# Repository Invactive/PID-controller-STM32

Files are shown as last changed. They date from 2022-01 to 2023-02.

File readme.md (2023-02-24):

# PID controller project - resistor temperature control

Temperature controller with PID regulator and live data logger. Implemented on development board NUCLEO-STM32F767ZI.

## Features
- Temperature setting via UART serial communication or phisical encoder (default start temperature is 20℃)
- Monitoring current measured value via UART serial communication
- Display of setpoint and current temperature on LCD display
- Python script for logging live data and displaying measured signals on graph
- Automatic control system controlled by a software-designed PID controller

## Components
-	Development board NUCLEO-STM32F767ZI
-	Ceramic heating resistor 22Ω, 5W
-	Power supply AC/DC - 5,7V/800mA DC
-	Supply module for contact plates MB102
-	Transistor MOSFET IRF520N
-	Temperature sensor (digital - I2C) BMP280
-	Rotary encoder
- Display - LCD 1602A

## Electrical schematics
[Schematics](./Screens_pdfs_txts/Schematics.pdf)

## Photos
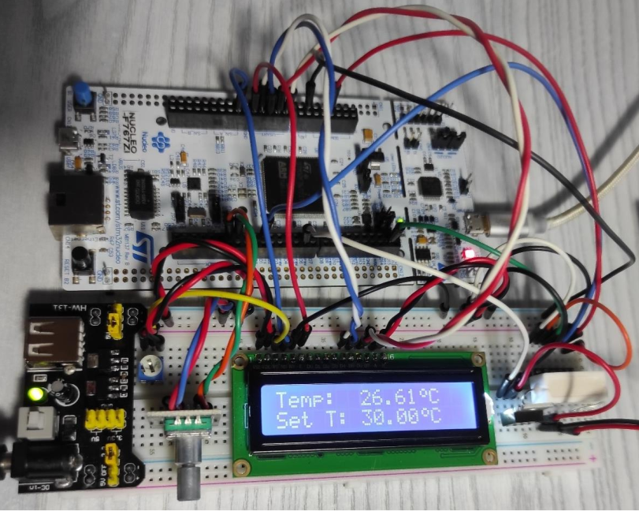
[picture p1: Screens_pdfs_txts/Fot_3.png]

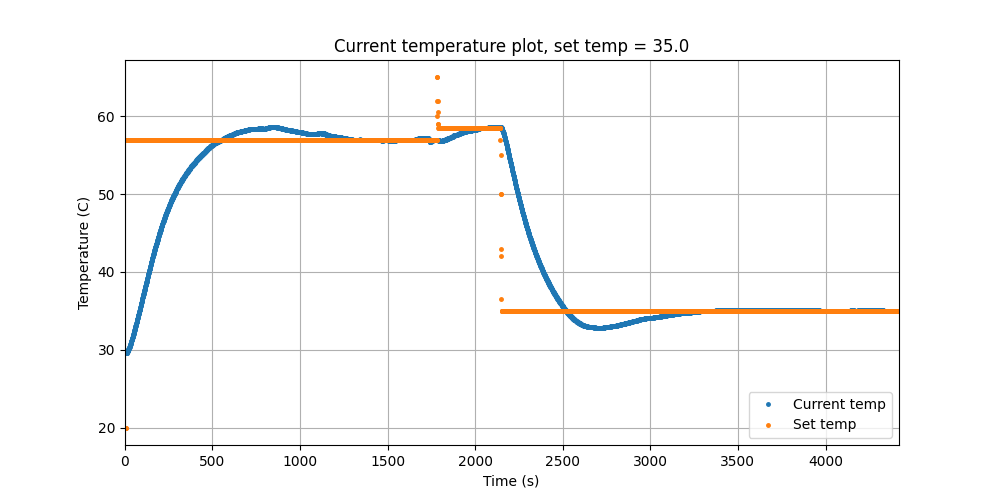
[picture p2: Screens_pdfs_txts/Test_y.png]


## Demonstration video
[Demo video on Youtube](https://youtu.be/86S8K2vb8bY)

## Resources:
- https://os.mbed.com/platforms/ST-Nucleo-F767ZI/
- https://msalamon.pl/dziecinnie-prosta-sprzetowa-obsluga-enkodera-na-stm32/
- https://www.electronics-tutorials.ws/pl/tranzystor/mosfet-jako-przelacznik.html
- https://msalamon.pl/dostalismy-swietna-obsluge-przerwania-uart-idle-w-halu/
-	https://matplotlib.org/stable/index.html
-	https://www.researchgate.net/profile/Chris_Cox6/publication/316658102_First_order_plus_dead_time_FOPDT_model_parameter_estimation/links/5b2275ed0f7e9b0e37423cf6/Firs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

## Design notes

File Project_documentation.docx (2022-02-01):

Sprawozdanie z laboratorium | | Rok akademicki 2021/22
Przedmiot: Systemy mikroprocesorowe
Temat projektu: Projekt regulatora PID – regulacja temperatury rezystora | | Ostateczny termin złożenia: 31.01.2021
Wydział, kierunek, semestr, grupa: WARiE, AiR, sem. 5, Gr. A1/L2 | Imię i Nazwisko: 1. Jakub Grzesiak | Punkty:
Data złożenia ćwiczenia: 31.01.2022

1. Cel projektu

Celem projektu było zbudowanie i przetestowanie demonstracyjnego systemu sterowania i pomiaru temperatury obiektu cieplnego (rezystora) w oparciu o mikrokontroler z rodziny STM32. Zadaniem zaimplementowanego regulatora PID była regulacja temperatury z uchybem do 1% wartości zakresu regulacji. Do realizacji celu użyto płytkę ewaluacyjną NUCLEO-STM32F767ZI. Do symulacji i sprawdzania pomiarów posłużył Matlab i Python.

2. Spis użytych elementów
- Płytka ewaluacyjna NUCLEO-STM32F767ZI
- Rezystor ceramiczny 22 Ω , 5W
- Zasilacz sieciowy 5,7V/800mA DC
- Moduł zasilania MB102
- Tranzystor MOSFET IRF520N
- Czujnik temperatury BMP280
- Enkoder obrotowy
- Wyświetlacz LCD 1602A
3. Funkcjonalności projektu
- Zadawanie temperatury za pomocą komunikacji szeregowej UART lub enkodera (domyślna temperatura startowa to 20℃ , max. 65℃ )
- Podgląd aktualnej wartości mierzonej za pomocą komunikacji szeregowej UART
- Wyświetlanie zadawanej oraz aktualnej temperatury na wyświetlaczu LCD
- Skrypt Python do logowania danych na żywo i graficznego przedstawiania sygnałów pomiarowych
- Układ automatycznej regulacji sterowany za pomocą programowo zaprojektowanego regulatora PID
- System kontroli wersji GitHub
4. Schemat elektroniczny

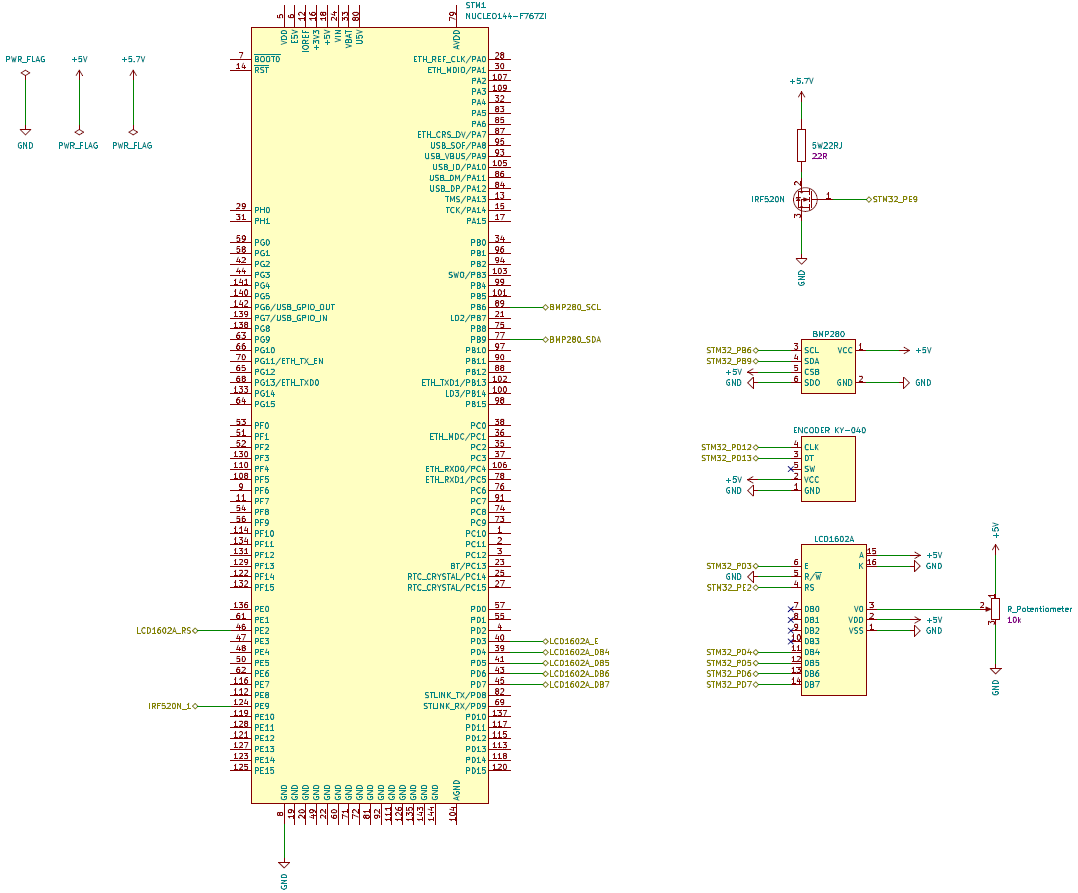
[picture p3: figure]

Schemat elektroniczny wykonano w programie KiCAD. Plik PDF schematu znajduje się w głównym folderze z dokumentacją.

Rysunek 1. Schemat elektroniczny projektu

5. Skrypt Python do logowania danych na żywo

Skrypt posiada następujące funkcjonalności:

- Pozwala na zadanie żądanej wartości temperatury
- Odczytuje aktualną oraz zadaną wartość temperatury przesyłaną przez port szeregowy COM z mikroprocesora
- Zapisuje czas od uruchomienia, aktualną wartość temperatury z czujnika oraz wartość zadaną temperatury do pliku .csv
- Wykreśla graficzny przebieg temperatury mierzonej przez czujnik BMP280 na żywo

Przy starcie skryptu należy podać numer portu szeregowego COM z którego pobierane będą dane oraz zadać temperaturę jaką ma osiągnąć obiekt (zakres od 20 do 65 ℃ ). Do działania skryptu wymagane jest posiadanie bibliotek w nim użytych – gdy nie są zainstalowane można użyć narzędzia pip install. Do wczytywania danych i wysyłania komend przez port szeregowy użyto biblioteki pyserial. Aby zakończyć pracę programu należy zamknąć okno wykresu ‘krzyżykiem’ bądź nacisnąć dowolny klawisz gdy aktywne jest okno figure. Następnie wykres wyłaczy się, a dane oraz wykres zostaną zapisane. Listing kodu został przedstawiony na końcu dokumentacji.

6. Model Matlab/Simulink i analiza obiektu oraz dobór nastaw regulatora

Do wykonania modelu obiektu wykorzystano dane pomiarowe zebrane przy wymuszeniu wypełnieniem 100%, czyli pełną wartością napięcia zasilania ~5,7V . Poniżej przedstawiono przebieg narastania temperatury rezystora w czasie wykreślony przez skrypt Python:

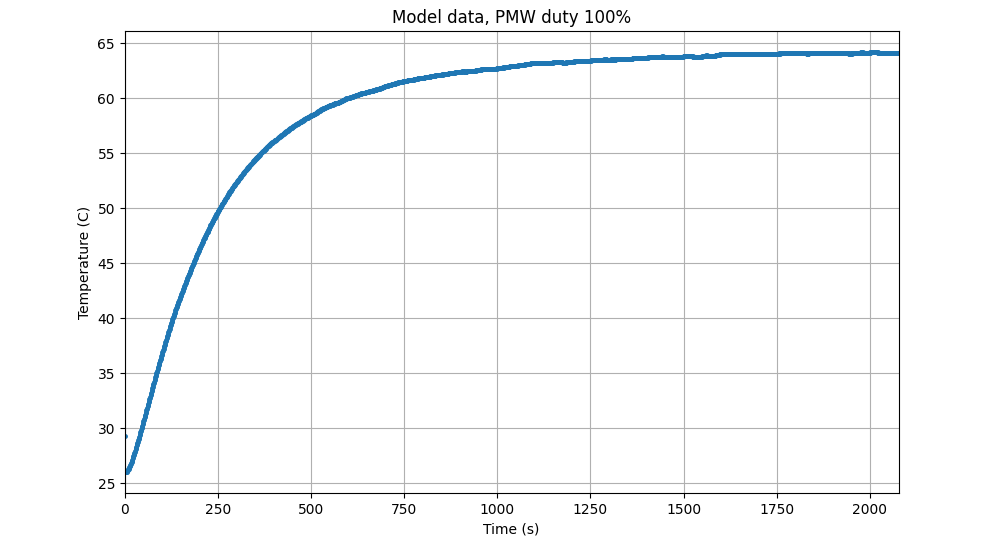
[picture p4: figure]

Rysunek 2. Wykres przebiegu temperatury przy wymuszeniu maksymalnym sygnałem sterującym

Przebieg wskazuje na obiekt o charakterze inercyjnym z opóźnieniem transportowym. Przy podaniu na obiekt maksymalnego osiągalnego wymuszenia otrzymujemy maksymalną temperaturę około 64,1℃ . Do modelowania, od tej wartości należy odjąć offset (64,1-26,05=38,05℃) aby znormalizować wartości – przebieg będzie zaczynał się wtedy od wartości 0℃ .

Do wyznaczenia parametrów obiektu z odpowiedzi skokowej użyto narzędzia Curve Fitting Tool.

Wzór do dopasowania odpowiedzi skokowej do obiektu FOPDT zaczerpnięto z pracy “Curve fitting software for first order plus dead time (FOPDT) model parameter estimation using step or pulse response data: a tutorial” – link. Poniżej przedstawiono efekt działania narzędzia CFT:

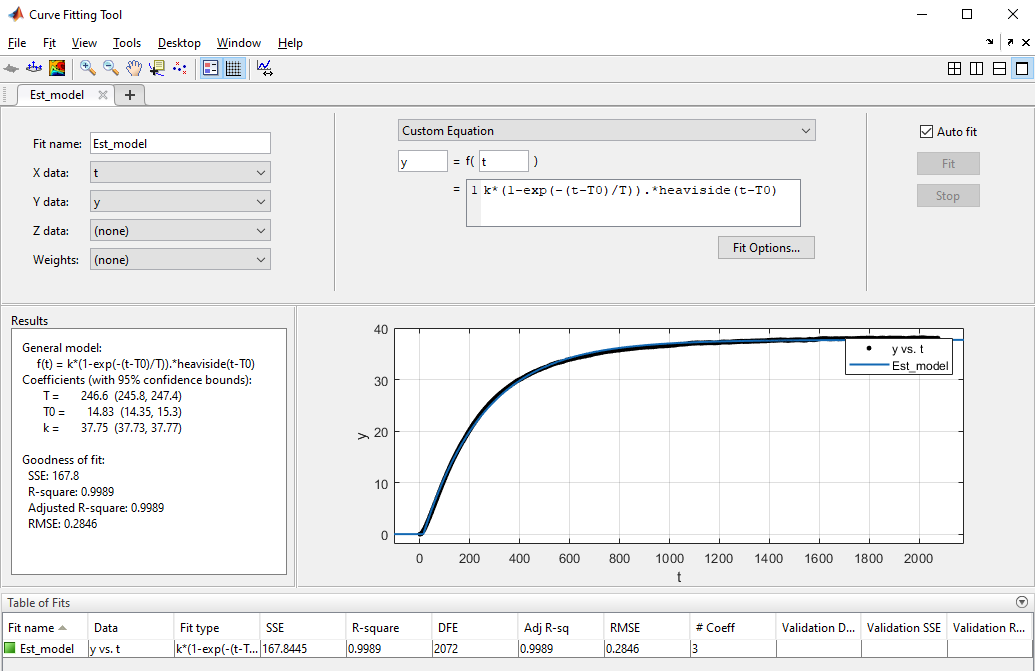
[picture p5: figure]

Rysunek 3. Identyfikacja parametrów obiektu z odpowiedzi skokowej

Estymowaną transmitancję można zatem przedstawić wzorem:

G_(est) (s)=k/(1+sT)e^(-sT_0) =(37,75)/(1+246,6s)e^(-14,83s)

Wzmocnienie k=37,75

Stała czasowa T=246,6

Opóźnienie transportowe T_0 =14,83

Poniżej przedstawiono porównanie odpowiedzi skokowych obiektu rzeczywistego i estymowanego:

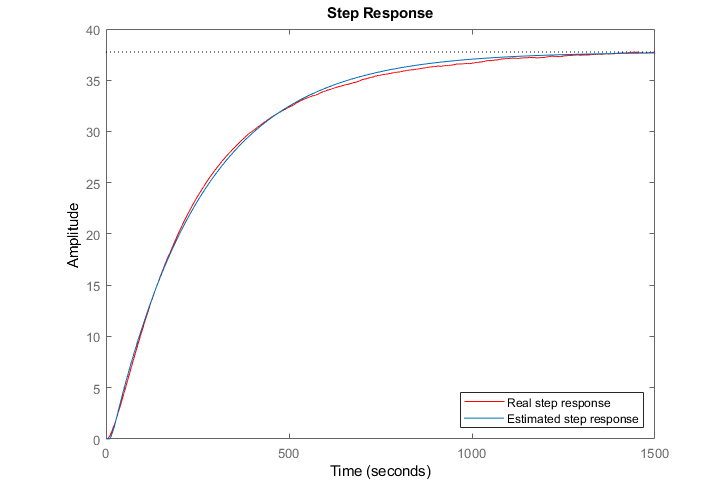
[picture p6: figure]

Rysunek 4. Porównanie odpowiedzi skokowych obiektu rzeczywistego i estymowanego

Odpowiedzi odpowiadają sobie, więc identyfikację można uznać za poprawnie wykonaną. Wszystkie pliki (skrypt Matlab i plik .sfit narzędzia CFToolbox znajdują się w folderze Matlab_files oraz na GitHubie). Listing kodu dodano także na końcu dokumentacji.

Doboru nastaw regulatora dokonano przy pomocy bloku Discrete PID Controller i narzędzia PID Tuner.

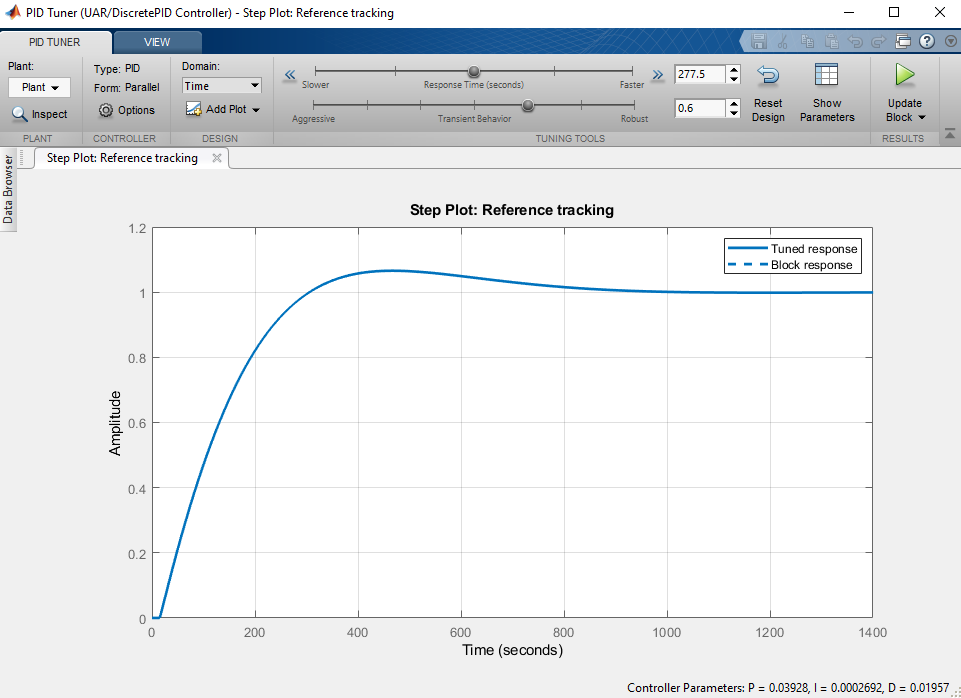
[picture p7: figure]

Rysunek 5. Dobór nastaw regulatora PID i odpowiedź obiektu w UAR z zaproponowanym regulatorem

Narzędzie PID Tuner pomogło dobrać nastawy, które pozwalają na spełnienie założenia niskiego uchybu ustalonego. Następnie nastawy zaimplementowano w programie mikroprocesora i zbadano odpowiedź układu. Nastawy jakie dobrano to:

K_p =0,03928

K_i =0,0002692

K_d =0,01957

Schemat blokowy UAR:

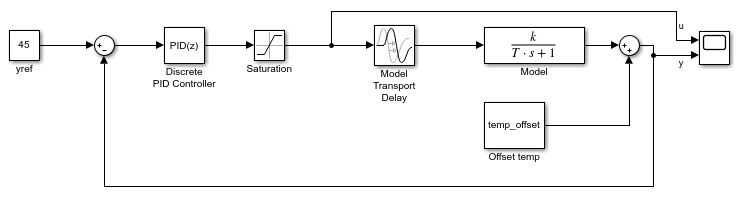
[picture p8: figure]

Rysunek 6. Schemat blokowy UAR

Rzeczywista odpowiedź układu z regulatorem PID i wyznaczonymi nastawami:


Rysunek 7. Przebieg wartości wyjściowej podczas testów projektu

Oraz przebieg sygnału sterującego wykreślony w Data Trace Timeline Graph:

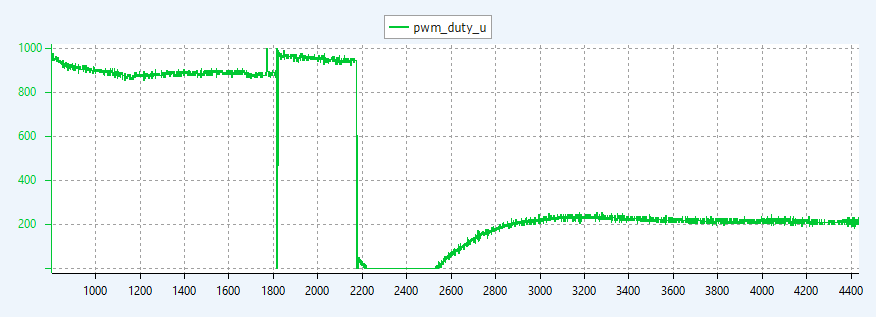
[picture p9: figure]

Rysunek 8. Przebieg sygnału sterującego podczas testów projektu

Jak widać na przebiegu, regulacja PID temperatury działa zgodnie z wymaganiami – temperatura odczytana czujnikiem stabilizuje się na zadanej wartości. Uchyb ustalony mieści się w granicy błędu zadanego 1%.

7. Opis rozwiązań zastosowanych w programie mikroprocesora
- Interfejs UART skonfigurowano w trybie Receive and Transmit oraz w trybie przerwaniowym NVIC i DMA. Przez ten interfejs można pobierać dane od użytkownika (temperatura zadana) oraz wysyłać dane do portu szeregowego w komputerze (aktualna temperatura i temperatura zadana). Poniżej przedstawiono Callback odbioru danych przez mikroprocesor:

main:

// Get setpoint value from user

HAL_UARTEx_ReceiveToIdle_DMA(&huart3, (uint8_t *)get_UART, 10);

while(1):

// Reset data from UART

memset(get_UART, 0, 10);

poza mainem:

// UART callback handling

void HAL_UARTEx_RxEventCallback(UART_HandleTypeDef *huart, uint16_t Size){

if(huart->Instance == USART3){

float tmp = atof(get_UART);

if(tmp < 20) set_temp_f = 20;

else if(tmp > 65) set_temp_f = 65;

else set_temp_f = tmp;

HAL_UARTEx_ReceiveToIdle_DMA(&huart3, (uint8_t *)get_UART, 10);

}

}

- Skonfigurowano interfejs I2C do obsługi czujnika BMP280
- Do obsługi czujnika BMP280 i wyświetlacza LCD użyto zewnętrznych bibliotek załączonych do projektu
- Skonfigurowano 3 timery:
  - TIM1 do sterowania sygnałem PWM sterującym bramką tranzystora IRF520N (max. wypełnienie = 999)
  - TIM3 w trybie przerwaniowym NVIC do wyzwalania pomiaru temperatury, wysyłania danych, obliczania sygnału sterującego (razem z nasyceniem) i sterowania tranzystorem co okres próbkowania T_p =1s :

poza mainem:

// TIMERS callback handling

void HAL_TIM_PeriodElapsedCallback(TIM_HandleTypeDef *htim){

if(htim->Instance == TIM3){

// TEMPERATURE

BMP280_ReadTemperatureAndPressure(&current_temp_f, &pressure);

sprintf(current_temp_ch_UART, "Current temperature: %.2f\n\r", current_temp_f);

HAL_UART_Transmit(&huart3, (uint8_t *)current_temp_ch_UART, sizeof(current_temp_ch_UART)-1, 1000);

sprintf((char*)set_temp_ch_UART, "Set temperature: %.2f\n\r", set_temp_f);

HAL_UART_Transmit(&huart3, (uint8_t*)set_temp_ch_UART, strlen(set_temp_ch_UART), 1000);

pwm_duty_f = (htim1.Init.Period * calculate_PID(&PID1, set_temp_f, current_temp_f));

// Saturation

if(pwm_duty_f < 0.0) pwm_duty_u = 0;

else if(pwm_duty_f > htim1.Init.Period) pwm_duty_u = htim1.Init.Period;

else pwm_duty_u = (uint16_t) pwm_duty_f;

//pwm_duty_u = htim1.Init.Period; // 100% PWM duty for creating model

__HAL_TIM_SET_COMPARE(&htim1, TIM_CHANNEL_1, pwm_duty_u);

}

}

- TIM4 w trybie pollingu do obsługi enkodera obrotowego:

main:

// Prevents from bugging set_temp_f when encoder counter value goes through 0

htim4.Instance->CNT = 65535 / 2;

while(1):

// ENCODER

enc_uint = __HAL_TIM_GET_COUNTER(&htim4);

enc_diff_int = enc_uint - prev_enc_uint;

if(enc_diff_int >= 2 || enc_diff_int <= -2){

enc_diff_int /= 2;

set_temp_f += 0.5 * enc_diff_int;

if(set_temp_f > 65) set_temp_f = 65;

if(set_temp_f < 20) set_temp_f = 20;

}

prev_enc_uint = enc_uint;

- Skonfigurowano obsługę wyświetlacza LCD w pętli głównej programu:

main:

LCD_init();

LCD_write_command(LCD_CLEAR_INSTRUCTION);

LCD_write_command(LCD_HOME_INSTRUCTION);

while(1):

// LCD

snprintf(current_temp_ch_LCD, LCD_MAXIMUM_LINE_LENGTH, "Temp: %.2f", current_temp_f);

LCD_write_text(current_temp_ch_LCD);

LCD_write_data(LCD_CHAR_DEGREE);

LCD_write_char('C');

snprintf(set_temp_ch_LCD, LCD_MAXIMUM_LINE_LENGTH, "Set T: %.2f", set_temp_f);

LCD_goto_line(1);

LCD_write_text(set_temp_ch_LCD);

LCD_write_data(LCD_CHAR_DEGREE);

LCD_write_char('C');

HAL_Delay(100);

LCD_write_text(" ");

LCD_write_command(LCD_HOME_INSTRUCTION);

- Zaimplementowano regulator PID oraz funkcję obliczającą sygnał sterujący:

poza mainem:

struct Controller{

float Kp;

float Ki;

float Kd;

float Tp;

float prev_error;

float prev_u_I;

};

float calculate_PID(struct Controller *PID, float set_temp, float meas_temp){

float u = 0;

float error;

float u_P, u_I , u_D;

error = set_temp - meas_temp;

// Proportional

u_P = PID->Kp * error;

// Integral

u_I = PID->Ki * PID->Tp / 2.0 * (error + PID->prev_error) + PID->prev_u_I;

PID->prev_u_I = u_I;

// Derivative

u_D = (error - PID->prev_error) / PID->Tp;

PID->prev_error = error;

// Sum of P, I and D components

u = u_P + u_I + u_D;

return u;

}

struct Controller PID1;

main:

// Initialize PID Controller parameters and init data

PID1.Kp = 0.03928;

PID1.Ki = 0.0002692;

PID1.Kd = 0.01957;

PID1.Tp = 1;

PID1.prev_error = 0;

PID1.prev_u_I = 0;

8. Zdjęcia fizycznego układu

Poniżej przedstawiono wygląd rzeczywistego układu zbudowanego na płytce prototypowej:

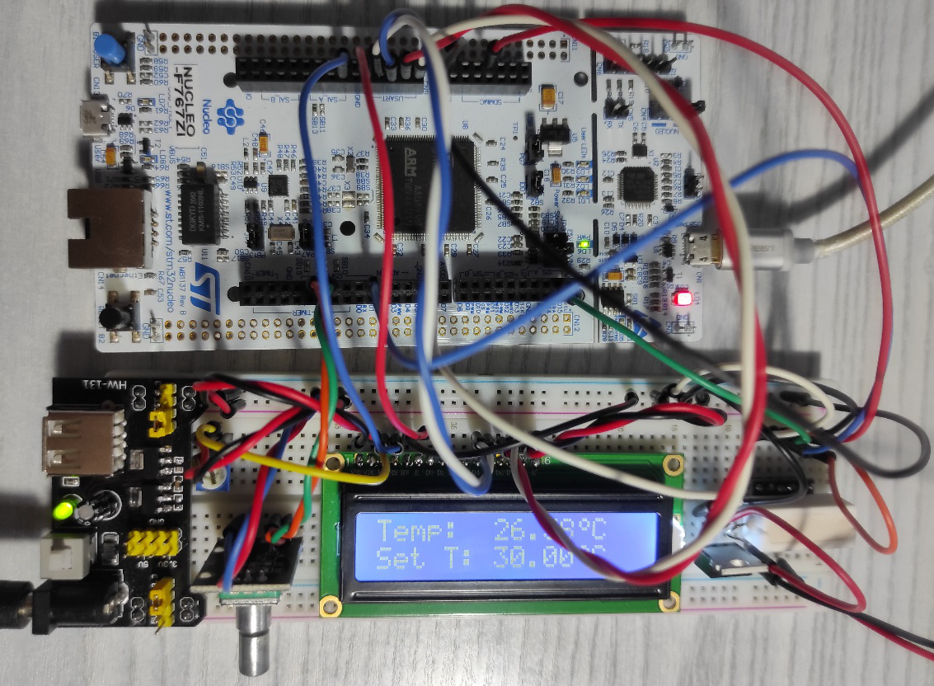
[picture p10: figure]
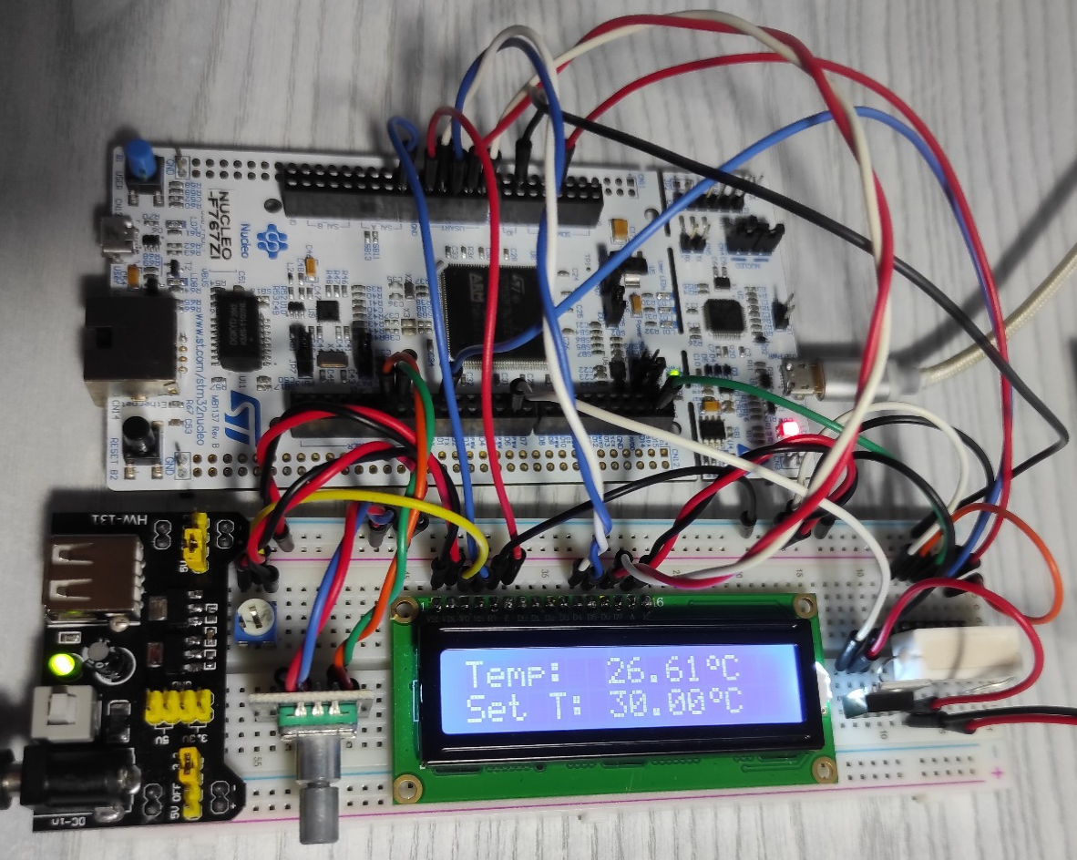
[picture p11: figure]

Rysunek 9. Zdjęcia fizycznego układu

9. Link do repozytorium Github

Kompletny projekt na mikroprocesor STM32, skrypt Python, Matlab oraz pełną dokumentację zamieszczono jako publiczne repozytorium Github pod linkiem:

https://github.com/JakubGrzesiak/SM---Final-Project.git

Listing kodu Python:

import serial #pip install pyserial
import matplotlib.pyplot as plt
import time
import csv

# Init variables/arrays
t = 0
Tp = 1 # sampling time [s]
curr_temp_samples = []
curr_temp_flag = 0
set_temp_samples = []
set_temp_flag = 0
timebase = []
d = bytearray() # serial read buffer

# Handling plot close event
close_flag = 1
def handle_close(event):
global close_flag
close_flag = 0
print("Data logging finished!")

# Figure init
fig = plt.figure(figsize=(10,6))
fig.canvas.mpl_connect('key_press_event', handle_close)
fig.canvas.mpl_connect('close_event', handle_close)
plt.ion()

# Saving data to .csv file
timestr = time.strftime("%Y%m%d-%H%M%S")
data = open("data_{}.csv".format(timestr) , 'w', newline='')
writer = csv.writer(data, delimiter=',')
header = ["Time", "Curr_temp", "Set_temp"]
writer.writerow(header)

# For debugging
# UART = serial.Serial("COM4", 115200, timeout=1, parity=serial.PARITY_NONE)
# set_start_temp = "30.00"

# User input
COM_PORT = int(input("Serial port number: "))
UART = serial.Serial("COM{}".format(COM_PORT), 115200, timeout=1, parity=serial.PARITY_NONE)
set_start_temp = str(input("Set temperature: "))
UART.write(set_start_temp.encode())

while close_flag:
if UART.inWaiting() >= 0:
d += UART.read(1)
if b"Current temperature: " in d:
curr_temp = UART.read(5)
curr_temp = curr_temp.decode()
curr_temp = float(curr_temp)
curr_temp_samples.append(curr_temp)
d[::] = b""
curr_temp_flag = 1
print("Current temperature:", curr_temp)
elif b"Set temperature: " in d:
set_temp = UART.read(5)
set_temp = set_temp.decode()
set_temp = float(set_temp)
set_temp_samples.append(set_temp)
d[::] = b""
set_temp_flag = 1
print("Set temperature:", set_temp)

if curr_temp_flag and set_temp_flag:
# Prepare x label for plot
timebase.append(t)
t += Tp
print("Timebase:", timebase)

# Plotting data
plt.clf()
plt.grid(True)
plt.plot(timebase, curr_temp_samples, '.', markersize=5, label="Current temp")
plt.plot(timebase, set_temp_samples, '.', markersize=5, label="Set temp")
plt.xlim(0, t + 1)
plt.title("Current temperature plot, set temp = {}".format(set_temp))
# plt.title("Model data, PMW duty 100%") # Used for model identification
plt.xlabel("Time (s)")
plt.ylabel("Temperature (C)")
plt.legend(loc="lower right")
plt.show(block=False)
fig.canvas.flush_events()
plt.pause(0.0001)
writer.writerow([timebase[-1], curr_temp_samples[-1], set_temp_samples[-1]])
curr_temp_flag = 0
set_temp_flag = 0

if close_flag == 0:
break

fig.savefig("Temp_plot_{}.png".format(timestr))
UART.close()
data.close()

Listing kodu Matlab:

% clear all; close all; clc;

% Read and parse data

data = dlmread('Model_data.csv', ',', 2, 0);

t = data(:,1);

y = data(:,2);

temp_offset = y(1);

yr = 64.1 - temp_offset;

y = y - y(1); % normalize data (start from 0)

% Plot step response

plot(t, y, 'r');

title("Normalized model data, PMW duty 100%");

xlabel("Time (s)");

ylabel("Temperature (C)");

xlim([0 max(t)]);

% Estimated transfer function

k = 37.75;

T = 246.6;

T0 = 14.83;

est_model = tf([k], [T 1], 'InputDelay', T0);

hold on;

step(est_model);

legend("Real step response", "Estimated step response", 'Location', 'southeast');

% PID controller in simulink

sim('UAR.slx')

Bibliografia/Źródła

- https://os.mbed.com/platforms/ST-Nucleo-F767ZI
- https://msalamon.pl/dziecinnie-prosta-sprzetowa-obsluga-enkodera-na-stm32
- https://www.electronics-tutorials.ws/pl/tranzystor/mosfet-jako-przelacznik.html
- https://msalamon.pl/dostalismy-swietna-obsluge-przerwania-uart-idle-w-halu/
- https://matplotlib.org/stable/index.html
- https://www.researchgate.net/profile/Chris_Cox6/publication/316658102_First_order_plus_dead_time_FOPDT_model_parameter_estimation/links/5b2275ed0f7e9b0e37423cf6/Firs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

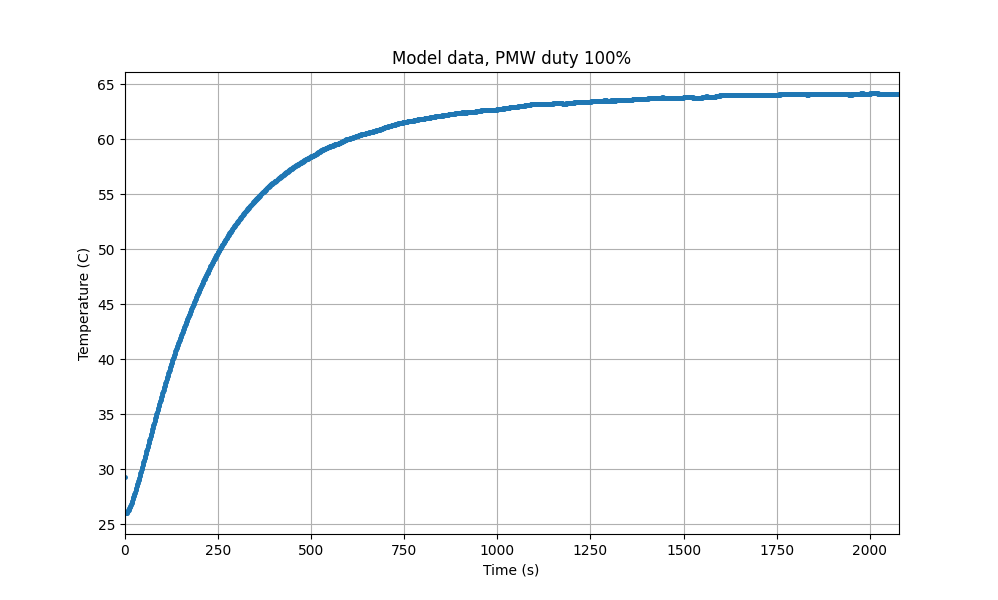
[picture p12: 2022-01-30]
Screens_pdfs_txts/Model_plot.png

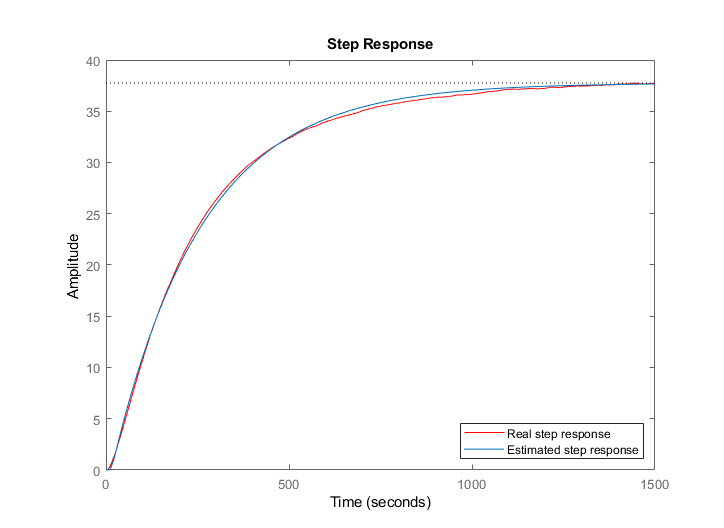
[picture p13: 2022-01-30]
Screens_pdfs_txts/Real_estimated_models.png

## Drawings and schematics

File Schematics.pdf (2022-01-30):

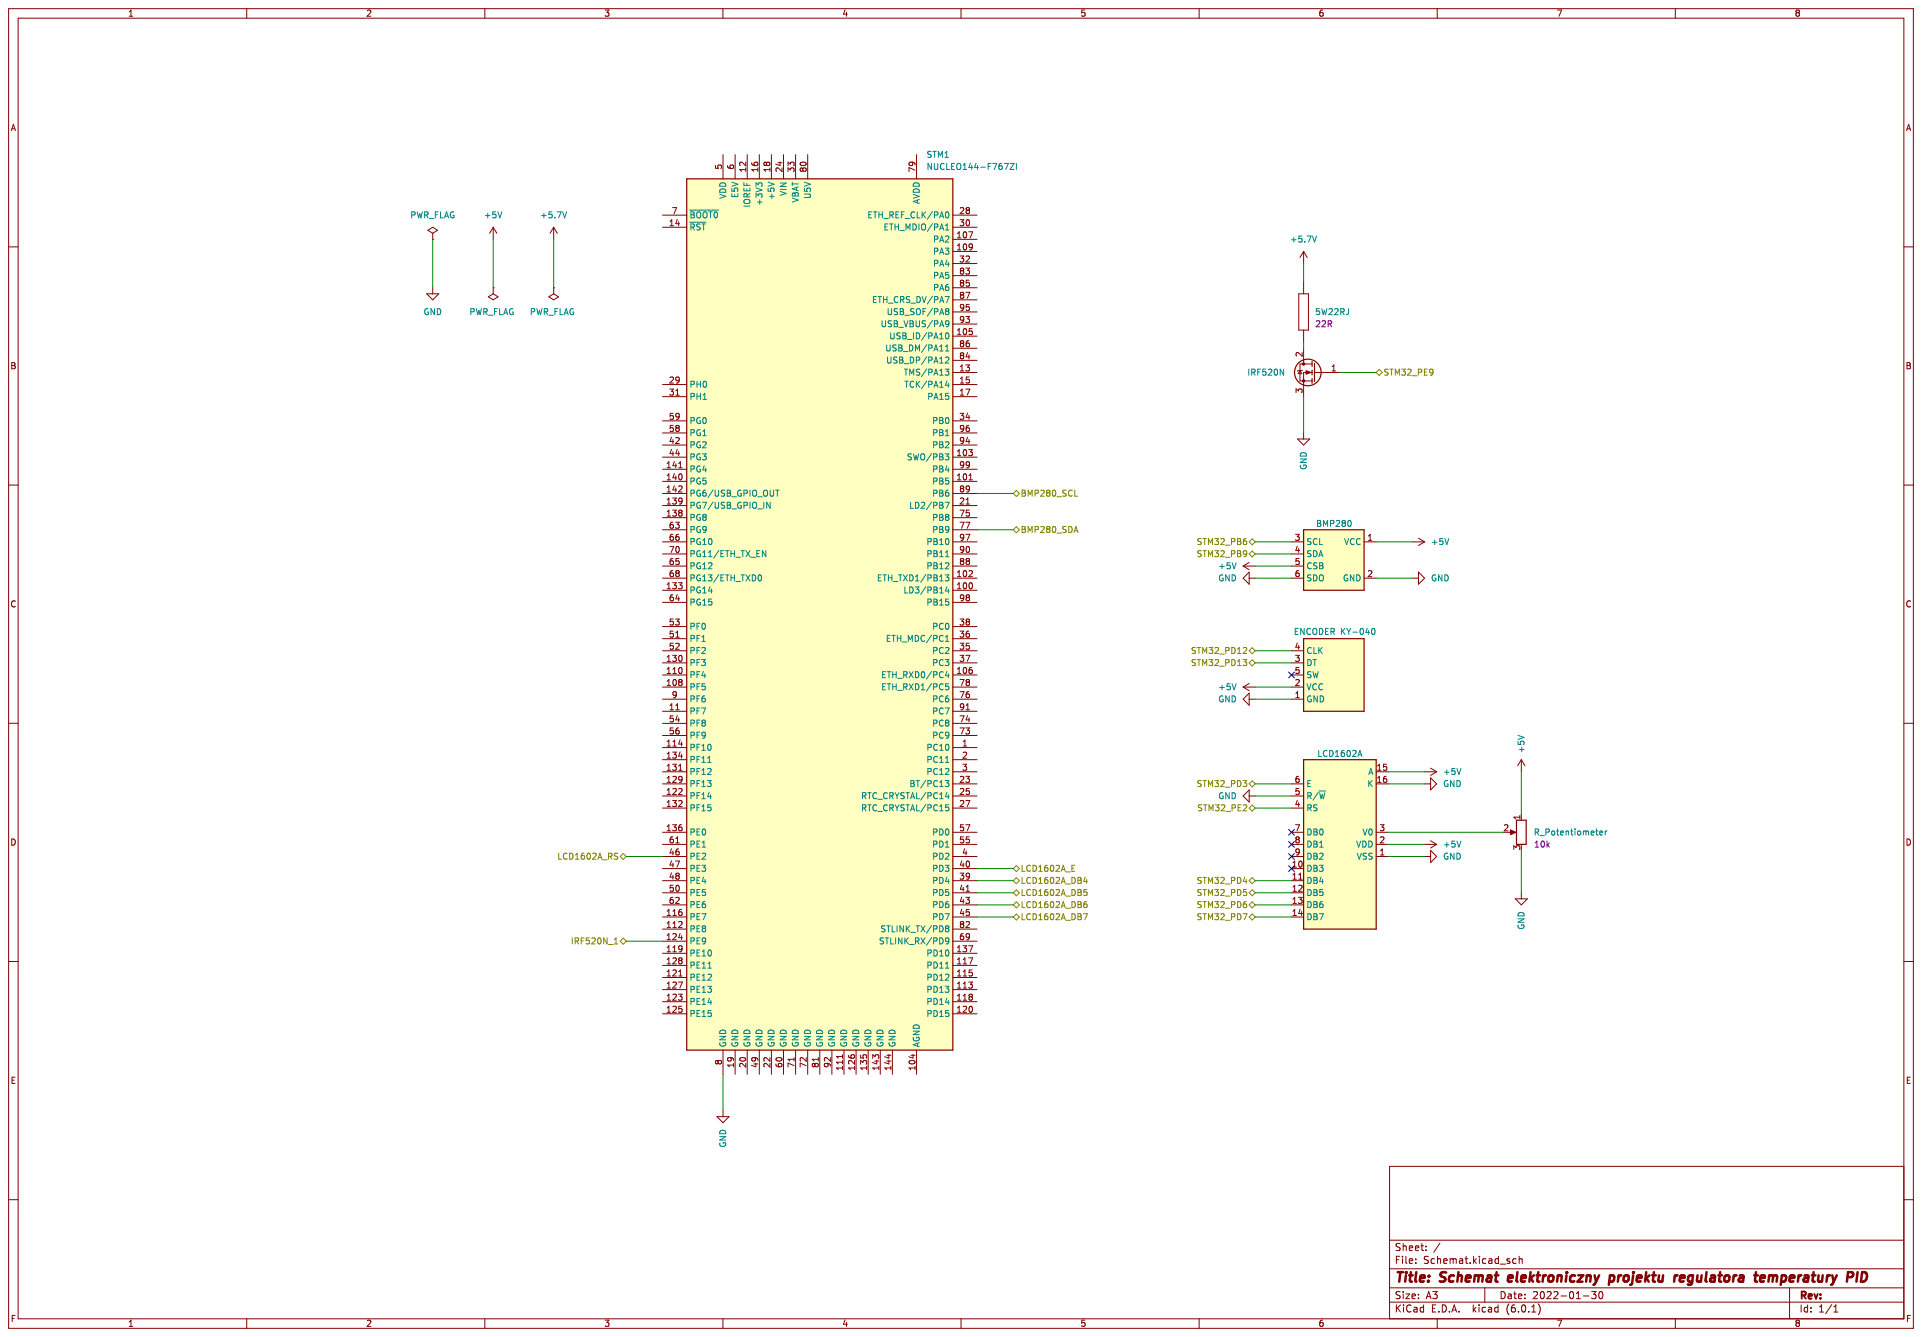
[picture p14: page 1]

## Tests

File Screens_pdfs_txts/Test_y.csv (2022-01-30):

Time | Curr_temp | Set_temp
0 | 29.6 | 20.0
1 | 29.6 | 20.0
2 | 29.59 | 20.0
3 | 29.59 | 20.0
4 | 29.6 | 20.0
5 | 29.59 | 20.0
6 | 29.59 | 56.99
7 | 29.59 | 56.99
8 | 29.61 | 56.99
9 | 29.61 | 56.99
10 | 29.63 | 56.99
11 | 29.64 | 56.99
12 | 29.67 | 56.99
13 | 29.69 | 56.99
14 | 29.74 | 56.99
15 | 29.78 | 56.99
16 | 29.82 | 56.99
17 | 29.85 | 56.99
18 | 29.9 | 56.99
19 | 29.96 | 56.99
20 | 30.0 | 56.99
21 | 30.05 | 56.99
22 | 30.1 | 56.99
23 | 30.16 | 56.99
24 | 30.22 | 56.99
25 | 30.28 | 56.99
26 | 30.34 | 56.99
27 | 30.39 | 56.99
28 | 30.46 | 56.99
29 | 30.52 | 56.99
30 | 30.59 | 56.99
31 | 30.64 | 56.99
32 | 30.72 | 56.99
33 | 30.79 | 56.99
34 | 30.84 | 56.99
35 | 30.92 | 56.99
36 | 31.0 | 56.99
37 | 31.07 | 56.99
38 | 31.14 | 56.99
39 | 31.23 | 56.99
40 | 31.3 | 56.99
41 | 31.37 | 56.99
42 | 31.45 | 56.99
43 | 31.51 | 56.99
44 | 31.6 | 56.99
45 | 31.69 | 56.99
46 | 31.75 | 56.99
47 | 31.83 | 56.99
48 | 31.92 | 56.99
49 | 31.99 | 56.99
50 | 32.08 | 56.99
51 | 32.16 | 56.99
52 | 32.24 | 56.99
53 | 32.32 | 56.99
54 | 32.39 | 56.99
55 | 32.5 | 56.99
56 | 32.59 | 56.99
57 | 32.66 | 56.99
58 | 32.74 | 56.99
59 | 32.85 | 56.99
60 | 32.92 | 56.99
61 | 33.01 | 56.99
62 | 33.1 | 56.99
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

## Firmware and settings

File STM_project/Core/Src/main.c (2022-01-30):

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
/* Includes ------------------------------------------------------------------*/
#include "main.h"

/* USER CODE BEGIN Includes */
#include "stdio.h"
#include "string.h"
#include "stdlib.h"
#include "BMPXX80.h"
#include "LCD.h"


/* USER CODE END Includes */


I2C_HandleTypeDef hi2c1;

TIM_HandleTypeDef htim1;
TIM_HandleTypeDef htim3;
TIM_HandleTypeDef htim4;

UART_HandleTypeDef huart3;
DMA_HandleTypeDef hdma_usart3_rx;

PCD_HandleTypeDef hpcd_USB_OTG_FS;

/* USER CODE BEGIN PV */
float current_temp_f;
char current_temp_ch_UART[29];
char current_temp_ch_LCD[29];
float set_temp_f = 20.0;

char set_temp_ch_UART[24];
char set_temp_ch_LCD[24];
int32_t pressure;

uint32_t enc_uint;
static uint32_t prev_enc_uint = 65535 / 2;
int32_t enc_diff_int;

char enc_ch[64];

float pwm_duty_f;
uint16_t pwm_duty_u = 0;

char get_UART[10];


/* USER CODE END PV */

void SystemClock_Config(void);
static void MX_GPIO_Init(void);
static void MX_DMA_Init(void);
static void MX_USART3_UART_Init(void);
static void MX_USB_OTG_FS_PCD_Init(void);
static void MX_I2C1_Init(void);
static void MX_TIM1_Init(void);
static void MX_TIM3_Init(void);
static void MX_TIM4_Init(void);
static void MX_NVIC_Init(void);
/* USER CODE BEGIN 0 */
struct Controller{
	float Kp;
	float Ki;
	float Kd;
	float Tp;
	float prev_error;
	float prev_u_I;

};


float calculate_PID(struct Controller *PID, float set_temp, float meas_temp){
	float u = 0;
	float error;
	float u_P, u_I , u_D;

	error = set_temp - meas_temp;

	// Proportional
	u_P = PID->Kp * error;

	// Integral
	u_I = PID->Ki * PID->Tp / 2.0 * (error + PID->prev_error) + PID->prev_u_I;
	PID->prev_u_I = u_I;

	// Derivative
	u_D = (error - PID->prev_error) / PID->Tp;

	PID->prev_error = error;

	// Sum of P, I and D components
	u = u_P + u_I + u_D;

	return u;
}

struct Controller PID1;



/* USER CODE END 0 */

/**
  * @brief  The application entry point.
  * @retval int
  */
int main(void)
{
  /* MCU Configuration--------------------------------------------------------*/

  /* Reset of all peripherals, Initializes the Flash interface and the Systick. */
  HAL_Init();

  /* Configure the system clock */
  SystemClock_Config();

  /* Initialize all configured peripherals */
  MX_GPIO_Init();
  MX_DMA_Init();
  MX_USART3_UART_Init();
  MX_USB_OTG_FS_PCD_Init();
  MX_I2C1_Init();
  MX_TIM1_Init();
  MX_TIM3_Init();
  MX_TIM4_Init();

  /* Initialize interrupts */
  MX_NVIC_Init();
  /* USER CODE BEGIN 2 */

  // TIM1 used used for controlling MOSFET with PWM
  HAL_TIM_PWM_Start(&htim1, TIM_CHANNEL_1);

  // TIM3 used for sampling temperature and PID controller
  HAL_TIM_Base_Start_IT(&htim3);

  // TIM4 used for encoder
  HAL_TIM_Encoder_Start(&htim4, TIM_CHANNEL_ALL);

  // BMP280 (temperature sensor) init
  BMP280_Init(&hi2c1, BMP280_TEMPERATURE_16BIT, BMP280_STANDARD, BMP280_FORCEDMODE);

  // Prevents from bugging set_temp_f when encoder counter value goes through 0
  htim4.Instance->CNT = 65535 / 2;

  LCD_init();
  LCD_write_command(LCD_CLEAR_INSTRUCTION);
  LCD_write_command(LCD_HOME_INSTRUCTION);
  HAL_Delay(2000);

  // Initialize PID Controller parameters and init data
  PID1.Kp = 0.03928;
  PID1.Ki = 0.0002692;
  PID1.Kd = 0.01957;
  PID1.Tp = 1;
  PID1.prev_error = 0;
  PID1.prev_u_I = 0;

  // Get setpoint value from user
  HAL_UARTEx_ReceiveToIdle_DMA(&huart3, (uint8_t *)get_UART, 10);


  /* USER CODE END 2 */

  /* Infinite loop */
  /* USER CODE BEGIN WHILE */
  while (1)
  {
    /* USER CODE END WHILE */

    /* USER CODE BEGIN 3 */

	  // ENCODER
	  enc_uint = __HAL_TIM_GET_COUNTER(&htim4);	// enc_uint = htim4.Instance->CNT;
	  enc_diff_int = enc_uint - prev_enc_uint;
	  if(enc_diff_int >= 2 || enc_diff_int <= -2){
		  enc_diff_int /= 2;
		  set_temp_f += 0.5 * enc_diff_int;
		  if(set_temp_f > 65) set_temp_f = 65;
		  if(set_temp_f < 20) set_temp_f = 20;
	  }
	  prev_enc_uint = enc_uint;

	  // LCD
	  snprintf(current_temp_ch_LCD, LCD_MAXIMUM_LINE_LENGTH, "Temp:  %.2f", current_temp_f);
	  LCD_write_text(current_temp_ch_LCD);
	  LCD_write_data(LCD_CHAR_DEGREE);
	  LCD_write_char('C');
	  snprintf(set_temp_ch_LCD, LCD_MAXIMUM_LINE_LENGTH, "Set T: %.2f", set_temp_f);
	  LCD_goto_line(1);
	  LCD_write_text(set_temp_ch_LCD);
	  LCD_write_data(LCD_CHAR_DEGREE);
	  LCD_write_char('C');
	  HAL_Delay(100);
	  LCD_write_text("                ");
	  LCD_write_command(LCD_HOME_INSTRUCTION);

	  // Reset data from UART
	  memset(get_UART, 0, 10);

  }
  /* USER CODE END 3 */
}

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
/* USER CODE BEGIN 4 */
// TIMERS callback handling
void HAL_TIM_PeriodElapsedCallback(TIM_HandleTypeDef *htim){
	if(htim->Instance == TIM3){
		// TEMPERATURE
		BMP280_ReadTemperatureAndPressure(&current_temp_f, &pressure);
		sprintf(current_temp_ch_UART, "Current temperature: %.2f\n\r", current_temp_f);
		HAL_UART_Transmit(&huart3, (uint8_t *)current_temp_ch_UART, sizeof(current_temp_ch_UART)-1, 1000);

		sprintf((char*)set_temp_ch_UART, "Set temperature: %.2f\n\r", set_temp_f);
		HAL_UART_Transmit(&huart3, (uint8_t*)set_temp_ch_UART, strlen(set_temp_ch_UART), 1000);

		pwm_duty_f = (htim1.Init.Period * calculate_PID(&PID1, set_temp_f, current_temp_f));

		// Saturation
		if(pwm_duty_f < 0.0) pwm_duty_u = 0;
		else if(pwm_duty_f > htim1.Init.Period) pwm_duty_u = htim1.Init.Period;
		else pwm_duty_u = (uint16_t) pwm_duty_f;

//		pwm_duty_u = htim1.Init.Period;		// 100% PWM duty for creating model
		__HAL_TIM_SET_COMPARE(&htim1, TIM_CHANNEL_1, pwm_duty_u);

	}

}

// UART callback handling
void HAL_UARTEx_RxEventCallback(UART_HandleTypeDef *huart, uint16_t Size){
	if(huart->Instance == USART3){
		float tmp = atof(get_UART);
		if(tmp < 20) set_temp_f = 20;
		else if(tmp > 65) set_temp_f = 65;
		else set_temp_f = tmp;

		HAL_UARTEx_ReceiveToIdle_DMA(&huart3, (uint8_t *)get_UART, 10);
	}
}

/* USER CODE END 4 */
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


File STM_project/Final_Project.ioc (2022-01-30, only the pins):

Mcu.UserName=STM32F767ZITx
PA1.GPIO_Label=RMII_REF_CLK [LAN8742A-CZ-TR_REFCLK0]
PA1.Signal=ETH_REF_CLK
PA10.GPIO_Label=USB_ID
PA10.Signal=USB_OTG_FS_ID
PA11.GPIO_Label=USB_DM
PA11.Signal=USB_OTG_FS_DM
PA12.GPIO_Label=USB_DP
PA12.Signal=USB_OTG_FS_DP
PA13.GPIO_Label=TMS
PA13.Signal=SYS_JTMS-SWDIO
PA14.GPIO_Label=TCK
PA14.Signal=SYS_JTCK-SWCLK
PA2.GPIO_Label=RMII_MDIO [LAN8742A-CZ-TR_MDIO]
PA2.Signal=ETH_MDIO
PA7.GPIO_Label=RMII_CRS_DV [LAN8742A-CZ-TR_CRS_DV]
PA7.Signal=ETH_CRS_DV
PA8.GPIO_Label=USB_SOF [TP1]
PA8.Signal=USB_OTG_FS_SOF
PA9.GPIO_Label=USB_VBUS
PA9.Signal=USB_OTG_FS_VBUS
PB0.GPIO_Label=LD1 [Green]
PB0.Signal=GPIO_Output
PB13.GPIO_Label=RMII_TXD1 [LAN8742A-CZ-TR_TXD1]
PB13.Signal=ETH_TXD1
PB14.GPIO_Label=LD3 [Red]
PB14.Signal=GPIO_Output
PB3.GPIO_Label=SWO
PB3.Signal=SYS_JTDO-SWO
PB6.Signal=I2C1_SCL
PB7.GPIO_Label=LD2 [Blue]
PB7.Signal=GPIO_Output
PB9.Signal=I2C1_SDA
PC1.GPIO_Label=RMII_MDC [LAN8742A-CZ-TR_MDC]
PC1.Signal=ETH_MDC
PC13.GPIO_Label=USER_Btn [B1]
PC13.Signal=GPXTI13
PC14/OSC32_IN.Signal=RCC_OSC32_IN
PC15/OSC32_OUT.Signal=RCC_OSC32_OUT
PC4.GPIO_Label=RMII_RXD0 [LAN8742A-CZ-TR_RXD0]
PC4.Signal=ETH_RXD0
PC5.GPIO_Label=RMII_RXD1 [LAN8742A-CZ-TR_RXD1]
PC5.Signal=ETH_RXD1
PD12.GPIO_Label=ENC_CLK
PD12.Signal=S_TIM4_CH1
PD13.GPIO_Label=ENC_DT
PD13.Signal=S_TIM4_CH2
PD3.GPIO_Label=LCD_Enable
PD3.Signal=GPIO_Output
PD4.GPIO_Label=LCD_DATA4
PD4.Signal=GPIO_Output
PD5.GPIO_Label=LCD_DATA5
PD5.Signal=GPIO_Output
PD6.GPIO_Label=LCD_DATA6
PD6.Signal=GPIO_Output
PD7.GPIO_Label=LCD_DATA7
PD7.Signal=GPIO_Output
PD8.Signal=USART3_TX
PD9.Signal=USART3_RX
PE2.GPIO_Label=LCD_RS
PE2.Signal=GPIO_Output
PE9.Signal=S_TIM1_CH1
PG11.GPIO_Label=RMII_TX_EN [LAN8742A-CZ-TR_TXEN]
PG11.Signal=ETH_TX_EN
PG13.GPIO_Label=RMII_TXD0 [LAN8742A-CZ-TR_TXD0]
PG13.Signal=ETH_TXD0
PG6.GPIO_Label=USB_PowerSwitchOn [STMPS2151STR_EN]
PG6.Signal=GPIO_Output
PG7.GPIO_Label=USB_OverCurrent [STMPS2151STR_FAULT]
PG7.Signal=GPIO_Input
PH0/OSC_IN.GPIO_Label=MCO [STM32F103CBT6_PA8]
PH0/OSC_IN.Signal=RCC_OSC_IN
PH1/OSC_OUT.Signal=RCC_OSC_OUT

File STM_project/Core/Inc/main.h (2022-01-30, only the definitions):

#define LCD_RS_Pin GPIO_PIN_2
#define LCD_RS_GPIO_Port GPIOE
#define USER_Btn_Pin GPIO_PIN_13
#define USER_Btn_GPIO_Port GPIOC
#define MCO_Pin GPIO_PIN_0
#define MCO_GPIO_Port GPIOH
#define RMII_MDC_Pin GPIO_PIN_1
#define RMII_MDC_GPIO_Port GPIOC
#define RMII_REF_CLK_Pin GPIO_PIN_1
#define RMII_REF_CLK_GPIO_Port GPIOA
#define RMII_MDIO_Pin GPIO_PIN_2
#define RMII_MDIO_GPIO_Port GPIOA
#define RMII_CRS_DV_Pin GPIO_PIN_7
#define RMII_CRS_DV_GPIO_Port GPIOA
#define RMII_RXD0_Pin GPIO_PIN_4
#define RMII_RXD0_GPIO_Port GPIOC
#define RMII_RXD1_Pin GPIO_PIN_5
#define RMII_RXD1_GPIO_Port GPIOC
#define LD1_Pin GPIO_PIN_0
#define LD1_GPIO_Port GPIOB
#define RMII_TXD1_Pin GPIO_PIN_13
#define RMII_TXD1_GPIO_Port GPIOB
#define LD3_Pin GPIO_PIN_14
#define LD3_GPIO_Port GPIOB
#define ENC_CLK_Pin GPIO_PIN_12
#define ENC_CLK_GPIO_Port GPIOD
#define ENC_DT_Pin GPIO_PIN_13
#define ENC_DT_GPIO_Port GPIOD
#define USB_PowerSwitchOn_Pin GPIO_PIN_6
#define USB_PowerSwitchOn_GPIO_Port GPIOG
#define USB_OverCurrent_Pin GPIO_PIN_7
#define USB_OverCurrent_GPIO_Port GPIOG
#define USB_SOF_Pin GPIO_PIN_8
#define USB_SOF_GPIO_Port GPIOA
#define USB_VBUS_Pin GPIO_PIN_9
#define USB_VBUS_GPIO_Port GPIOA
#define USB_ID_Pin GPIO_PIN_10
#define USB_ID_GPIO_Port GPIOA
#define USB_DM_Pin GPIO_PIN_11
#define USB_DM_GPIO_Port GPIOA
#define USB_DP_Pin GPIO_PIN_12
#define USB_DP_GPIO_Port GPIOA
#define TMS_Pin GPIO_PIN_13
#define TMS_GPIO_Port GPIOA
#define TCK_Pin GPIO_PIN_14
#define TCK_GPIO_Port GPIOA
#define LCD_Enable_Pin GPIO_PIN_3
#define LCD_Enable_GPIO_Port GPIOD
#define LCD_DATA4_Pin GPIO_PIN_4
#define LCD_DATA4_GPIO_Port GPIOD
#define LCD_DATA5_Pin GPIO_PIN_5
#define LCD_DATA5_GPIO_Port GPIOD
#define LCD_DATA6_Pin GPIO_PIN_6
#define LCD_DATA6_GPIO_Port GPIOD
#define LCD_DATA7_Pin GPIO_PIN_7
#define LCD_DATA7_GPIO_Port GPIOD
#define RMII_TX_EN_Pin GPIO_PIN_11
#define RMII_TX_EN_GPIO_Port GPIOG
#define RMII_TXD0_Pin GPIO_PIN_13
#define RMII_TXD0_GPIO_Port GPIOG
#define SWO_Pin GPIO_PIN_3
#define SWO_GPIO_Port GPIOB
#define LD2_Pin GPIO_PIN_7
#define LD2_GPIO_Port GPIOB

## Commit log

2022-01-14 BMP and UART
2022-01-16 LCD, BMP280 and encoder handling
2022-01-18 timers configured
2022-01-23 Implemented PID regulator da sd a sd
2022-01-30 Final version
    [Model_data.csv, Schemat.kicad_pcb, Schemat.kicad_sch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]

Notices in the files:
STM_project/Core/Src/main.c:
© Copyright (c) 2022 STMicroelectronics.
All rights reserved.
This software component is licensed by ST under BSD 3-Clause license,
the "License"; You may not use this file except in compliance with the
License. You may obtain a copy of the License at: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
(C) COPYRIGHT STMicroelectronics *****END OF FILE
